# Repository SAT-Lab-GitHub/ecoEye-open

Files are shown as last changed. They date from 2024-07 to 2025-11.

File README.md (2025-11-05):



>[!CAUTION]
>Crrently-shipped openMV H7+ boards run a refactored firmware that is not backwards-compatible with our published scripts. The breaking changes appeared in version 4.5.6 [(more info)](https://forums.openmv.io/t/openmv-firmware-v4-5-6-and-up-tensorflow-porting-guide/9863). The last firmware version that supported our scripts' execution should be 4.3.0 [(official download here)](https://github.com/openmv/openmv/releases/tag/v4.3.0).

Computer-assisted design (CAD) and electronic design automation (EDA) files, as well as micropython scripts (muPy) for building and running ecoEye, an embedded computer-vision camera for ecological applications.

Detailed assembly instructions can be found in the [Wiki](https://github.com/SAT-Lab-GitHub/ecoEye-open/wiki).

The corresponding scientific article is in print. The pre-print is on [BiorXiv](https://www.biorxiv.org/content/10.1101/2023.07.26.550656v1).

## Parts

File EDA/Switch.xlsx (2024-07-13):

Item | Quantity | Reference | Value | Part | Mfg P/N | Size | Supplier Parts | Comment
1 | 1 | U |  | MOSFET P-CH 20V 4A SOT23-3 | DMG3415U-7 | SOT-23-3 | C96616 | P-Channel 20 V 4A (Ta) 900mW (Ta) Surface Mount SOT-23-3
2 | 1 | U1 |  | IC GATE NAND 4CH 2-INP 14TSSOP | MC14093BDG | 14-SOIC | C233506 (https://lcsc.com/product-detail/Gates_onsemi-MC14093BDG_C233506.html) | NAND Gate IC 4 Channel Schmitt Trigger 14-TSSOP
3 | 1 | S2 |  | SWITCH TACTILE SPST-NO 0.05A 24V | B3F-4000 |  | C87494 | Tactile Switch SPST-NO Top Actuated Through Hole
4 | 1 | Q |  | TRANS NPN 45V 0.1A SOT-23 | BC847B | SOT-23-3 | C8575 | Bipolar (BJT) Transistor NPN 100MHz Surface Mount SOT-23-3
5 | 2 | R1, R4 | 1K | RES 1K OHM 0.1% 1/8W 0805 | ERA-6AEB102V | 6-0805_N | C17513 | 1 kOhms ±0.1% 0.125W, 1/8W Chip Resistor 0805 (2012 Metric) Automotive AEC-Q200 Thin Film
6 | 2 | R2, R3 | 100K | RES SMD 100K OHM 0.1% 1/4W 0805 | RP73PF2A100KBTDF | 6-0805_N | C55868 | 100 ±0.1% 0.25W, 1/4W Chip Resistor 0805 (2012 Metric) - Thin Film
7 | 1 | C1 | 0.1 uF | CAP CER 0.1UF 50V X7R 0805 | C2012X7R1H104K085AA | C0805 | C49678 | 0.1 µF ±10% 50V Ceramic Capacitor X7R 0805 (2012 Metric)
9 | 1 | P2 |  |  | 901210764 |  | C293357

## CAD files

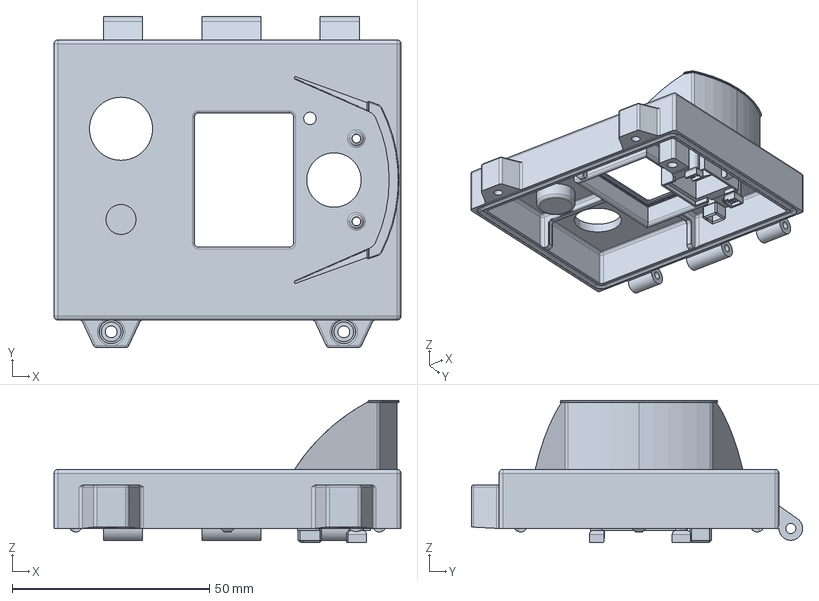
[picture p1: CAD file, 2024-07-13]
CAD/Frontside_V49.stp
88.0 x 84.0 x 36.1 mm

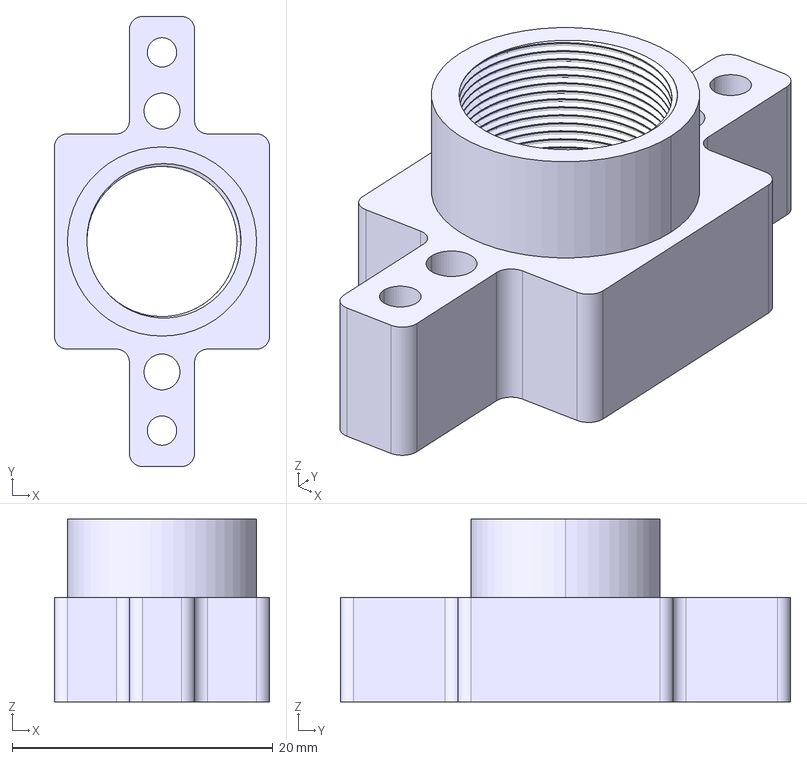
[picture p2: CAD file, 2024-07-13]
CAD/Standalone_Lensmount_thread_V23.stp
16.5 x 34.5 x 14.0 mm

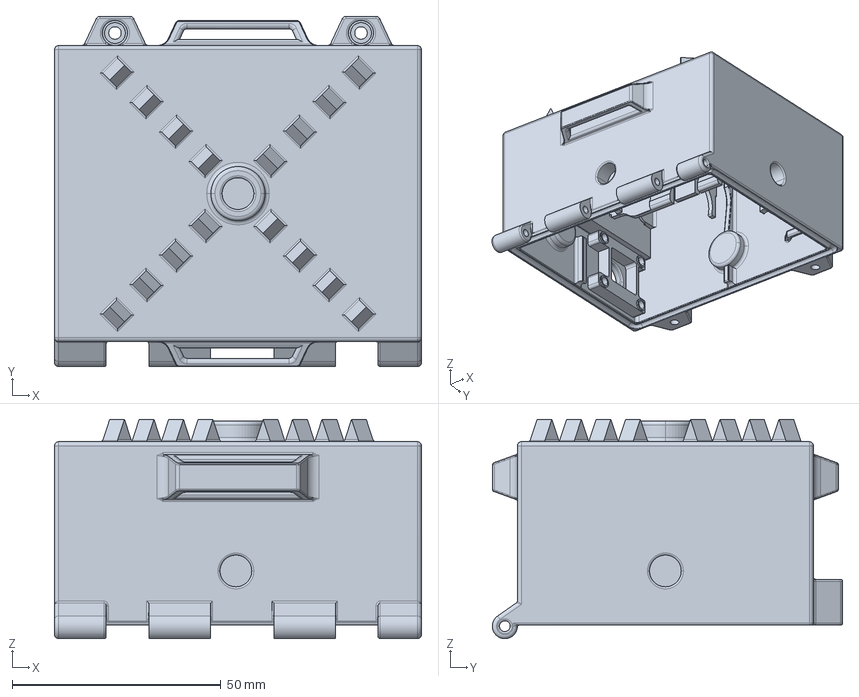
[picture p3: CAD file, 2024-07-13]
CAD/BacksideV49.stp
88.0 x 84.0 x 52.6 mm

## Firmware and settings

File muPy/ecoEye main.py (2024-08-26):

# Blob detection and image classification with whole image, image subsets, ROI, or blob-detected bounding rectangles
# bold character generator : lingojam.com/BoldLetters
# title horizontal lines : copyandpastesymbols.net/line-symbols.html
#import libraries
import sensor, image, time, os, tf, pyb, machine, sys, uos, gc, math
from pyb import Pin, Timer
# import external functions
from ecofunctions import *
# perform quick start from sleep check
start_check()

# ╋╋╋╋╋╋╋╋╋╋ 𝙐𝙎𝙀𝙍-𝘿𝙀𝙁𝙄𝙉𝙀𝘿 𝙋𝘼𝙍𝘼𝙈𝙀𝙏𝙀𝙍𝙎 ╋╋╋╋╋╋╋╋╋╋

# ━━━━━━━━━━ 𝗦𝗛𝗢𝗥𝗧𝗖𝗨𝗧 𝗠𝗢𝗗𝗘𝗦 ━━━━━━━━━━
#operation mode:
#0: live view. Disables saving pictures, frame differencing, classifying, sleeping, bracketing, delay between pictures. Uses auto-exposure.
#1: deploy or test (do not override settings listed below)
#2: live capture. Disables frame differencing, classifying, sleeping, bracketing, delay between pictures. Uses auto-exposure.
MODE = 1

# ━━━━━━━━━━ 𝗚𝗘𝗡𝗘𝗥𝗔𝗟 ━━━━━━━━━━
#camera ID: enter the ID written on the H7+ board's QR code sticker
camera_ID = "00000"
#whether the power management system is used or not
PMS = False
#whether the voltage divider circuit is plugged or not
voltage_divider = False

# ━━━━━━━━━━ 𝗜𝗠𝗔𝗚𝗘 ━━━━━━━━━━
#what resolution to use
sensor_framesize = sensor.WQXGA2
#sensor image format. Options:
#RGB565 = color
#GRAYSCALE = black & white)
sensor_pixformat = sensor.RGB565
#whether to digitally zoom into image
sensor_windowing = False
#introduce delay between pictures (seconds). Otherwise with a delay of 0, the camera runs at maximum speed
delay_loop_s = 0
#for saving whole images or regions of interest (ROIs). Options:
#none: save no picture
#all: save all pictures (fd_enable must be False)
#trigger: save image-change-triggered pictures
#detect: save images with model-detected patterns
save_roi = "all"

# ⚊⚊⚊⚊⚊ windowing mode only parameters ⚊⚊⚊⚊⚊
#rectangle tuples (x,y coordinates and width and height) for digital zoom. x=0,y=0 is conventionally the upper left corner.
#windowing_x=324 corresponds to the point from which a central square crop can be taken while using all the vertical resolution of the sensor
windowing_x = 324
windowing_y = 0
windowing_w = 1944
windowing_h = 1944

# ⚊⚊⚊⚊⚊ advanced settings ⚊⚊⚊⚊⚊
#whether to use user-defined rois (regions of interest)
use_roi = False
rois = [(197,742,782,753),(1309,1320,560,460)]
#whether to control number of frame buffers
sensor_framebuffers_control = False
sensor_framebuffers = 1
#threshold above which the camera goes to sleep between pictures to save power. Below that threshold, the camera will stay on and simply wait
delay_threshold_sleep_s = 10
#set JPEG quality (90: ~1 MB, 95: ~2MB, 100: ~7MB). Hardly discernible improvement above 93
#0: minimum
#100: maximum
jpeg_quality = 95

# ━━━━━━━━━━ 𝗘𝗫𝗣𝗢𝗦𝗨𝗥𝗘 ━━━━━━━━━━
#exposure control mode. Options:
#auto: camera continuously adjusts exposure time and gain, not compatible with frame differencing-based detection
#bias: adjusting exposure and gain automatically at regular intervals (time period can be defined below) but with a user-defined bias for exposure time and gain
#exposure: fixing exposure time, while adjusting gain at regular intervals (time period can be defined below)
#manual: fixing exposure time and gain
exposure_control = "exposure"
#whether to use exposure bracketing
exposure_bracketing = False

# ⚊⚊⚊⚊⚊ bias mode only parameters ⚊⚊⚊⚊⚊
#settings for bias mode: This is the user-defined multiplicative bias for the exposure time. Multiplies the automatic exposure time with this value. Values above 1 brighten the image, values below 1 darken it.
#for instance, if your subject has a bright background (e.g., sky) during the day, you may use values above 1 for the day bias
#if your subject is more strongly illuminated by the IR LEDs than the background during the night, use values below 1 for the night bias
exposure_bias_day = 1
exposure_bias_night = 1
#gain user-bias. Multiplies the automatically-determined gain with this value. Values above 1 brighten the image, values below 1 darken it.
gain_bias = 1
# ⚊⚊⚊⚊⚊ manual or exposure mode only parameters ⚊⚊⚊⚊⚊
#setting for manual and exposure mode:
exposure_ms = 20
#setting for manual mode:
gain_dB = 24

# ⚊⚊⚊⚊⚊ advanced settings ⚊⚊⚊⚊⚊
# How often to adjust exposure, if not in manual or auto mode
expose_period_s = 60
# multiplicative exposure factors used for exposure bracketing, given in tuple. Sequence matters. Lowers frames per second.
exposure_bracketing_values = [1,0.5,2]

# ━━━━━━━━━━ 𝗜𝗟𝗟𝗨𝗠𝗜𝗡𝗔𝗧𝗜𝗢𝗡 𝗟𝗘𝗗 ━━━━━━━━━━
#whether the light shield or IR LED module is installed
#this parameter is only used to determine the voltage divider values
LED_module = False
# which LEDs to use
# module : installed LED module, can be IR or White LEDs
# onboard : use onboard IR LEDs
LED_select = "onboard"
#operation mode for onboard IR or module LEDs at night. Options:
#on: continuously ON during night time . Should be used for continuous illumination with frame differencing
#blink: power-saving intermittent powering on. Should be used to save power, but only when using models to detect targets, since illumination will be unstable
#off: always OFF
LED_mode_night = "off"

# ⚊⚊⚊⚊⚊ LED module only parameters ⚊⚊⚊⚊⚊
#PWM (brightness) of the plug-in LED module
LED_module_PWM = 100
#how long to turn the LED module on (milliseconds) - should possibly not be longer than 3 seconds for IR module
LED_module_warmup = 3000
#how long to turn the LED module off (milliseconds) - should possibly be longer than 5 seconds for IR module
LED_module_cooldown = 0

# ━━━━━━━━━━ 𝗙𝗥𝗔𝗠𝗘 𝗗𝗜𝗙𝗙𝗘𝗥𝗘𝗡𝗖𝗜𝗡𝗚 ━━━━━━━━━━
#whether to use frame differencing. This subtracts every current image from a reference image, resulting in dark images when there is no change.
#a change will introduce a "blob" in the otherwise dark image, which can be detected, logged, and characterised
fd_enable = True

# ⚊⚊⚊⚊⚊ FD enabled only parameters ⚊⚊⚊⚊⚊
#action for blobs. options:
#stop: stop detecting blobs after the first one
#log: log all blobs in detections file
blob_action = "log"
#sensitivity of the blob detection, as measured by the area (number of pixels) of the blobs. Blobs outside this min-max range will not be logged.
#Blob areas can be estimated by drawing rectangular selections on the image preview with the mouse; the area will be displayed below
minimum_blob_pixels = 3000
maximum_blob_pixels = 500000
#color channel thresholds for detection. Pixels with color channel values outside of these ranges will be considered to be blobs.
#requires at least one tuple for grayscale images (for instance: [(0,5)]), three tuples for RGB565 images (for instance: [(0,3),(-3,3),(-3,3)] - this corresponds to LAB channels)
color_thresholds = [(0,5)]

# ⚊⚊⚊⚊⚊ advanced settings ⚊⚊⚊⚊⚊
#whether to export the detected blobs as jpegs (e.g., for gathering training images). options:
#rectangle: exports bounding rectangle
#square: exports bounding square with a side length of the longest side of the blob's bounding rectangle
#none: does not export blobs
export_blobs = "none"
# How much to blend by ([0-256]==[0.0-1.0]). NOTE that blending happens every time exposure is adjusted
background_blend_level = 128

# ━━━━━━━━━━ 𝗡𝗘𝗨𝗥𝗔𝗟 𝗡𝗘𝗧𝗪𝗢𝗥𝗞𝗦 ━━━━━━━━━━
#whether to us neural networks to analyse the image. options:
#image: classify the whole image (i.e. image classification)
#objects: detect (multiple) targets within image (i.e. object detection)
#blobs: classify the blobs (extracted from their bounding rectangles)
#none: do not use neural networks
# TODO give new variable name
classify_mode = "none"

# ⚊⚊⚊⚊⚊ classify enabled only parameters ⚊⚊⚊⚊⚊
#absolute file paths to model and labels files stored on SD card. needs to start with backslash if file is in root
net_path = "/trained.tflite"
labels_path = "/labels.txt"
# model resolution - used for re-scaling before image classification to get a better performance result
model_resolution = 320
#target confidence score above which the image is considered a detection and logged
threshold_confidence = 0.2
#define non-target label names to exclude from image classification results
non_target_labels = "Background"
# --- advanced settings
#minimum image scale for model input
minimum_image_scale = 1
#under which image scale image analysis should be deferred after sunset (with 0.5 overlapping windows in both directions, scale 0.5 takes 8 s, 0.25 takes 40 s, 0.125 takes 3 min)
threshold_image_scale_defer = 0.5

# ━━━━━━━━━━ 𝗜𝗡𝗗𝗜𝗖𝗔𝗧𝗢𝗥𝗦 ━━━━━━━━━━
#whether to show the LED signals and image markings. initialising, waking, sleeping, and regular blinking LED signals, as well as warnings are not affected
indicators = True
#how often to save status log
status_logging_period_ms = 10*60*1000

# ⚊⚊⚊⚊⚊ advanced settings ⚊⚊⚊⚊⚊
#period of blue LED indicating camera is active (in milliseconds, also works when indicators=False)
active_LED_interval_ms = 60*1000
#how long to turn on active LED
active_LED_duration_ms = 500
#how many voltage readings to average over to obtain the value that will be logged
voltage_readings = 10
#how much delay between voltage readings (in milliseconds)
voltage_readings_delay = 10
#minimum voltage for image sensor operation. theoretically, when voltage is below 2.7 V, the image sensor stops working
vbat_minimum = 0
# Add more colors if you are detecting more than 7 types of classes at once
colors = [(255,0,0),(0,255,0),(255,255,0),(0,0,255),(255,0,255),(0,255,255),(255,255,255)]

# ━━━━━━━━━━ 𝗧𝗜𝗠𝗘 𝗔𝗡𝗗 𝗣𝗢𝗪𝗘𝗥 ━━━━━━━━━━
#when the camera should work. options:
#night: during the night (between sunrise and sunset)
#day: during the day (between sunset and sunrise)
#24h: all the time
operation_time = "24h"
# select which RTC to use
# onboard : internal STM32 RTC (10 min offset every 6 hours)
# ds3231 : IR shield v3 shield (green) with ML621 coin cell battery
# pcf8563 : WUV shield (red) with CR1220 coin cell battery
RTC_select = 'onboard'
# For internal RTC, set the current date and time manually (year, month, day, weekday, hours, minutes, seconds, subseconds).
current_date_time = (2022, 9, 15, 0, 18, 33, 35, 0)
#defining operation times for camera, depending on its operation time mode
sunrise_hour = 5
sunrise_minute = 17
sunset_hour = 18
sunset_minute = 34

# ━━━━━━━━━━ 𝗖𝗢𝗡𝗡𝗘𝗖𝗧𝗜𝗩𝗧𝗬 ━━━━━━━━━━
# whether to use WiFi, WiFi shield needs to be installed
wifi_enable = False

# ⚊⚊⚊⚊⚊ wifi enabled only parameters ⚊⚊⚊⚊⚊
# Wifi name and password
wifi_ssid = "MiFiC14646"
wifi_key = "12345678"
# url link to image/data/notification hosting website
wifi_data_url = "https://api.thingspeak.com/update?api_key=WZRWZLO9PRNLY6Y7"
wifi_img_url = "http://potblitd.com/upload.php"
# which data to transfer (ATM only send_confidence is implemented)
send_confidence = False
send_image = False
send_differencing = False
send_voltage = False
#  ⚊⚊⚊⚊⚊ advanced setting ⚊⚊⚊⚊⚊
# confidence above which the image is sent over wifi
threshold_image = 0.5

# ╋╋╋╋╋╋╋╋╋╋ 𝙀𝙉𝘿 𝙊𝙁 𝙐𝙎𝙀𝙍-𝘿𝙀𝙁𝙄𝙉𝙀𝘿 𝙋𝘼𝙍𝘼𝙈𝙀𝙏𝙀𝙍𝙎 ╋╋╋╋╋╋╋╋╋╋

# ━━━━━━━━━━ 𝗦𝗛𝗢𝗥𝗧𝗖𝗨𝗧 𝗠𝗢𝗗𝗘𝗦 ━━━━━━━━━━
# override settings in ine of the shortcut modes
if (MODE == 0 or MODE == 2):
    fd_enable = False
    classify_mode = "none"
    operation_time = "24h"
    exposure_control = "auto"
    delay_loop_s = 0
    exposure_bracketing = False
    RTC_select = 'onboard'
    if (MODE == 0):
        save_roi = "none"
        print("*** Live view enabled! *** ")
    if (MODE == 2):
        save_roi = "all"
        print("*** Live capture enabled! ***")
# or not in normal mode
elif (MODE == 1): print("*** Deployment started! ***")

# ━━━━━━━━━━ 𝗩𝗢𝗟𝗧𝗔𝗚𝗘 𝗗𝗜𝗩𝗜𝗗𝗘𝗥 ━━━━━━━━━━
# resistors values on voltage divider circuits
R_1_PMS_LED = 30
R_2_PMS_LED = 8.82352941176
R_1_PMS_noLED = 30
R_2_PMS_noLED = 100
R_1_noPMS_LED = 2.88
R_2_noPMS_LED = 9.67741935484
R_1_noPMS_noLED = 200
R_2_noPMS_noLED = 680
# set the resistor values in ADC voltage divider
if(PMS):
    if (LED_module):
        R_1 = R_1_PMS_LED
        R_2 = R_2_PMS_LED
    else:
        R_1 = R_1_PMS_noLED
        R_2 = R_2_PMS_noLED
else:
    if (LED_module):
        R_1 = R_1_noPMS_LED
        R_2 = R_2_noPMS_LED
    else:
        R_1 = R_1_noPMS_noLED
        R_2 = R_2_noPMS_noLED

# create voltage divider class
vdiv_bat = vdiv(voltage_divider,voltage_readings,voltage_readings_delay,R_1,R_2)

# ━━━━━━━━━━ 𝗧𝗜𝗠𝗘 𝗦𝗘𝗧/𝗨𝗣𝗗𝗔𝗧𝗘 ━━━━━━━━━━
# create suntime class
solartime = suntime(operation_time,sunrise_hour,sunrise_minute,sunset_hour,sunset_minute)
# initialise RTC object
rtc = pyb.RTC()
# set rtc from user definedc date and time only on power on
if (machine.reset_cause() != machine.DEEPSLEEP_RESET and RTC_select == 'onboard'):
    rtc.datetime(current_date_time)
if(RTC_select == 'ds3231'):
    # import necessary librairies
    from ds3231 import DS3231
    # initialize i2c pins on P7 (SCL) and P8 (SDA) and DS3231 as ext_rtc
    i2c = machine.SoftI2C(sda=pyb.Pin('P8'), scl=pyb.Pin('P7'))
    ext_rtc = DS3231(i2c)
    ext_rtc.get_time(True)
if(RTC_select == 'pcf8563'):
    # import necessary librairies
    from pcf8563 import PCF8563
    # initialize i2c pins on P4 (SCL) and P5 (SDA) and PCF8563 as ext_rtc
    i2c = machine.SoftI2C(sda=pyb.Pin('P5'), scl=pyb.Pin('P4'))
    ext_rtc = PCF8563(i2c)
    ext_rtc.get_time(True)

# print date and time from set or updated RTC
print("Current date (Y,M,D):",rtc.datetime()[0:3],"and time (H,M,S):",rtc.datetime()[4:7])

# ━━━━━━━━━━ 𝗙𝗜𝗟𝗘𝗦 𝗔𝗡𝗗 𝗙𝗢𝗟𝗗𝗘𝗥𝗦 ━━━━━━━━━━
#import mobilenet model and labels before new directory is created
if (classify_mode != "none"):
    net = net_path
    try:
        labels = [line.rstrip('\n') for line in open(labels_path)]
        print("Loaded model and labels")
        #get target label index
        target_indices = [i for i in range(len(labels)) if labels[i] not in non_target_labels]
        non_target_indices = [i for i in range(len(labels)) if labels[i] in non_target_labels]
        print("Selected target indices:",list(labels[i] for i in target_indices))
    except Exception as e:
        print(e)
        raise Exception('Failed to load "trained.tflite" or "labels.txt", make sure to add these files on the SD card (' + str(e) + ')')

# On wakeup from deep sleep, fetch variables from files
if (machine.reset_cause() == machine.DEEPSLEEP_RESET):
    # retrieve current working folder name in VAR
    with open('/VAR/currentfolder.txt', 'r') as folderfetch:
        current_folder = folderfetch.read()
    # retrieve current picture ID in VAR
    with open('/VAR/picturecount.txt', 'r') as countfetch:
        picture_count = eval(countfetch.read())
    # retrieve current detection ID in VAR
    with open('/VAR/detectioncount.txt', 'r') as countfetch:
        detection_count = eval(countfetch.read())

    # check voltage and save status, if battery too low -> sleep until sunrise
    vbat = vdiv_bat.read_voltage()
    save_status(vbat,"Script start - Waking",current_folder)
    if (vbat!="NA" and vbat<vbat_minimum and not pyb.USB_VCP().isconnected()):
        save_variables(current_folder, picture_count, detection_count)
        save_status(vbat,"Battery low - Sleeping",current_folder)
        indicator_dsleep(solartime.time_until_sunrise()+30*60*1000,active_LED_interval_ms)

# create and initialize new folders only on powerup or soft reset
if (machine.reset_cause() != machine.DEEPSLEEP_RESET and MODE != 0):
    # if VAR folder doesnt exists,create new VAR folder
    if (not "VAR" in os.listdir()):
        os.mkdir('VAR')

    # Listing root contents to search folders
    files_jpegs_folder=os.listdir()
    folders=[files_jpegs_folder for files_jpegs_folder in files_jpegs_folder if "." not in files_jpegs_folder]
    if(len(folders)>0):
        folder_number=len(folders)
    else: folder_number=0
    #incrementing folder number (-1 because VAR folder)
    new_folder_number=int(folder_number)-1

    #create folder for new deployment to avoid overwriting images
    folder_created=False
    folder_time = rtc.datetime()
    while (not folder_created):
        try:
            current_folder=str(new_folder_number)+" "+"-".join(map(str,list(folder_time[i] for i in [0,1,2])))+"_"+"-".join(map(str,list(folder_time[i] for i in [4,5,6])))
            os.mkdir(str(current_folder))
            print("Created new deployment folder: "+str(current_folder))
            folder_created=True
        except:
            #increment by 1 if folder already exists, until it doesn't
            new_folder_number=new_folder_number+1

    # Create detection files
    if(not 'detections.csv' in os.listdir(str(current_folder))):
            with open(str(current_folder)+'/detections.csv', 'a') as detectionlog:
                detectionlog.write("detection_id" + ',' + "picture_id" + ',' + "blob_pixels" + ',' + "blob_elongation" + ','
          + "blob_corner1_x" + ',' + "blob_corner1_y" + ',' + "blob_corner2_x" + ',' + "blob_corner2_y" + ',' + "blob_corner3_x" + ',' + "blob_corner3_y" + ',' + "blob_corner4_x" + ',' + "blob_corner4_y"
          + ',' + "blob_l_mode" + ',' + "blob_l_min" + ',' + "blob_l_max" + ',' + "blob_a_mode" + ',' + "blob_a_min" + ',' + "blob_a_max" + ',' + "blob_b_mode" + ',' + "blob_b_min" + ',' + "blob_b_max" + ','
          + "image_labels" + ',' "image_confidences" + ',' + "image_x" + ',' + "image_y" + ',' + "image_width" + ',' + "image_height" + '\n')
    if(not 'images.csv' in os.listdir(str(current_folder))):
        with open(str(current_folder)+'/images.csv', 'a') as imagelog:
            imagelog.write("picture_id" + ',' + "date_time" + ',' + "exposure_us" + ',' + "gain_dB" + ',' + "frames_per_second" + ','
            + "image_type" + ',' + "roi_x" + ',' + "roi_y" + ',' + "roi_width" + ',' + "roi_height" + '\n')
    #make jpeg, reference image and ROI directories if needed
    if (not "jpegs" in os.listdir(str(current_folder))): os.mkdir(str(current_folder)+"/jpegs")
    if (fd_enable and not "reference" in os.listdir(str(current_folder)+"/jpegs")): os.mkdir(str(current_folder)+"/jpegs/reference")
    if (export_blobs!="none" and not "blobs" in os.listdir(str(current_folder)+"/jpegs")): os.mkdir(str(current_folder)+"/jpegs/blobs")
    if use_roi:
        for roi_temp in rois:
            if not '_'.join(map(str,roi_temp)) in os.listdir(str(current_folder)+"/jpegs"): os.mkdir(str(current_folder)+"/jpegs/"+'_'.join(map(str,roi_temp)))
            print("Created",'_'.join(map(str,roi_temp)),"subfolder(s)")

    #start counting
    picture_count = 0
    detection_count = 0

    # check voltage and save status, if battery too low -> sleep until sunrise
    vbat = vdiv_bat.read_voltage()
    save_status(vbat,"Script start - Initialising",current_folder)
    if (vbat!="NA" and vbat<vbat_minimum and not pyb.USB_VCP().isconnected()):
        save_variables(current_folder, picture_count, detection_count)
        save_status(vbat,"Battery low - Sleeping",current_folder)
        indicator_dsleep(solartime.time_until_sunrise()+30*60*1000,active_LED_interval_ms)

# ━━━━━━━━━━ 𝗕𝗢𝗔𝗥𝗗 𝗖𝗢𝗡𝗧𝗥𝗢𝗟 ━━━━━━━━━━
# verify that wifi shield is connected when wifi is enabled
if(wifi_enable):
    wifi_enable = wifishield_isconnnected()
# 50kHz pin6 timer2 channel1
light = Timer(2, freq=50000).channel(1, Timer.PWM, pin=Pin("P6"))
# init led status variables
LED_status = False

# ━━━━━━━━━━ 𝗣𝗜𝗖𝗧𝗨𝗥𝗘 𝗩𝗔𝗥𝗜𝗔𝗕𝗟𝗘𝗦 ━━━━━━━━━━
#user setting checks
if (fd_enable and exposure_control=="auto"):
    print("ATTENTION: using automatic exposure with frame differencing can result in spurious triggers!")
#determine exposure values
if (exposure_bracketing):
    exposure_values=exposure_bracketing_values
else:
    exposure_values=[1]
# ━━━━━━━━━━ 𝗦𝗘𝗡𝗦𝗢𝗥 𝗜𝗡𝗜𝗧 ━━━━━━━━━━
#indicate initialisation with LED
LED_WHITE_BLINK(200,3)
#check night time for continuous monitoring
night_time_check = not solartime.is_daytime()
# Reset and initialize the sensor
sensor.reset()
#we need RGB565 for frame differencing and MobileNet
sensor.set_pixformat(sensor_pixformat)
# Set frame size
sensor.set_framesize(sensor_framesize)
#windowing
if (sensor_windowing):
    sensor.set_windowing(windowing_x,windowing_y,windowing_w,windowing_h)
#set number of frame buffers
if sensor_framebuffers_control: sensor.set_framebuffers(sensor_framebuffers)
# Give the camera sensor time to adjust
sensor.skip_frames(time=1000)
# get future image width and height
if (sensor_windowing):
    image_width=windowing_w
    image_height=windowing_h
else:
    image_width=sensor.width()
    image_height=sensor.height()
#parameter validity checks
if (windowing_y+windowing_h>sensor.height()):
    print(windowing_y)
    print(windowing_h)
    print("sensor height:",sensor.height())
    sys.exit("Windowing height exceeds image height!")
if (windowing_x+windowing_w>sensor.width()):
    sys.exit("Windowing width exceeds image width!")

#assign roi to entire image if we do not use them
if(not use_roi and MODE != 0):
    rois = [(0,0,sensor.width(),sensor.height())]
    if not '_'.join(map(str,rois[0])) in os.listdir(str(current_folder)+"/jpegs"): os.mkdir(str(current_folder)+"/jpegs"+"/"+'_'.join(map(str,rois[0])))
    print("Created",'_'.join(map(str,rois[0])),"subfolder")

#adjusting exposure
# at night, turn ON selected illumination LEDs if not always OFF mode
if(LED_mode_night != "off" and night_time_check and LED_status == False):
    print("Turning illumination LEDs ON for exposure adjustment")
    if(LED_select == 'module'):
        print("Warming up LED module for",LED_module_warmup/1000,"seconds.")
        light.pulse_width_percent(LED_module_PWM)
        sensor.skip_frames(time = LED_module_warmup)
    if(LED_select == 'onboard'):
        LED_IR_ON()
    LED_status = True
expose(exposure_control,exposure_bias_day,exposure_bias_night,gain_bias,exposure_ms,gain_dB,night_time_check)
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

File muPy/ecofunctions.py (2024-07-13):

# Functions for EcoNect
# import libraries
import machine, pyb, time, network, sensor, os, urequests, math
from pyb import Pin, Timer, ExtInt
# import library for interrupt and allocate buffer memory
import micropython

##----- Function description -----#
## Reset and initialize the sensor
##----- Input arguments -----#
## sensor_framesize - resolution for the camera sensor
## sensor_pixformat - pixel format for the camera module
## sensor_windowing -
## sensor_framebuffers_control -
##----- Output variables -----#
## image_width, image_height
#def ecotime(RTC_select):
    #if (RTC_select == 'onboard'):
        #now = pyb.RTC().datetime()
        #return_time = (now[0],now[1],now[2],now[3],now[4],now[5],1,0)
    #if (RTC_select == 'ds3231'):
        #return_time = DS3231(machine.SoftI2C(sda=pyb.Pin('P8'), scl=pyb.Pin('P7'))).get_time()
    #if (RTC_select == 'pcf8563'):
        #from pcf8563 import PCF8563
        #return_time = PCF8563(machine.SoftI2C(sda=pyb.Pin('P5'), scl=pyb.Pin('P4'))).get_time()
    #return return_time

# ━━━━━━━━━━ 𝗖𝗔𝗠𝗘𝗥𝗔 𝗦𝗘𝗡𝗦𝗢𝗥 ━━━━━━━━━━
# ⚊⚊⚊⚊⚊ sensor inititlisation ⚊⚊⚊⚊⚊
# Reset and initialize the sensor
# --- Input arguments ---
# sensor_framesize - resolution for the camera sensor
# sensor_pixformat - pixel format for the camera module
# sensor_windowing -
# sensor_framebuffers_control :
# --- Output variables ---
# image_width, image_height
def sensor_init(sensor_framesize=sensor.QVGA,sensor_pixformat=sensor.RGB565,sensor_windowing=False,sensor_framebuffers_control=False):
    sensor.reset()
    #we need RGB565 for frame differencing and mobilenet
    sensor.set_pixformat(sensor_pixformat)
    # Set frame size
    sensor.set_framesize(sensor_framesize)
    #windowing
    #rect tuples (x,y coordinates and width and height) for digital zoom
    #x=0,y=0 is conventionally the upper left corner
    windowing_x = 324
    windowing_y = 0
    windowing_w = 1944
    windowing_h = 1944
    if (sensor_windowing):
        sensor.set_windowing(windowing_x,windowing_y,windowing_w,windowing_h)
    #set number of frame buffers
    sensor_framebuffers = 1
    if sensor_framebuffers_control: sensor.set_framebuffers(sensor_framebuffers)
    # Give the camera sensor time to adjust
    sensor.skip_frames(time=1000)
    # get future image width and height
    if (sensor_windowing):
        image_width=windowing_w
        image_height=windowing_h
    else:
        image_width=sensor.width()
        image_height=sensor.height()
    # return image width and height
    return image_width, image_height

# ⚊⚊⚊⚊⚊ Adjust exposure ⚊⚊⚊⚊⚊
# Adjust exposure
# --- Input arguments ---
# control - exposure control mode. Options: auto/bias/exposure/manual
# exposure_bias_day - automatic exposure time multiplicator at day
# exposure_bias_night - automatic exposure time multiplicator at night
# gain_bias - automatic exposure time multiplicator
# exposure_ms - manual exposure mode
# gain_dB - manual gain mode
# night_time_check - night time boolean
# LED_select - whether module or onboard LEDs are used
# LED_mode_night - LED mode : always on, always off or blink
# LED_module_warmup - LED startup time
# LED_module_PWM - brightness of the LEDs
# --- Output variables ----
# none
def expose(exposure_control,exposure_bias_day,exposure_bias_night,gain_bias,exposure_ms,gain_dB,night_time_check):
    print("Adjustment of exposure in",exposure_control,"mode...")

    if(exposure_control=="manual"):
        sensor.set_auto_exposure(False, exposure_us = exposure_ms*1000)
        sensor.set_auto_gain(False, gain_db = gain_dB)
        #wait for new exposure time to be applied (is it necessary?)
        sensor.skip_frames(time = 2000)
    elif(exposure_control=="exposure"):
        #enable auto exposure and gain
        sensor.set_auto_gain(True)
        sensor.set_auto_exposure(False, exposure_us = exposure_ms*1000)
        #wait for auto gain
        sensor.skip_frames(time = 2000)
        #fix the gain so image is stable for frame differencing
        sensor.set_auto_gain(False, gain_db = sensor.get_gain_db())
    elif(exposure_control=="bias"):
        if night_time_check: exposure_bias=exposure_bias_night
        else: exposure_bias=exposure_bias_day
        #enable auto exposure and gain
        sensor.set_auto_exposure(True)
        sensor.set_auto_gain(True)
        #wait for auto settings to kick in
        sensor.skip_frames(time = 2000)
            #apply bias
        sensor.set_auto_exposure(False, \
            exposure_us = int(sensor.get_exposure_us() * exposure_bias))
        sensor.set_auto_gain(False, \
            gain_db = sensor.get_gain_db() * gain_bias)
        #wait for bias to be applied
        sensor.skip_frames(time = 2000)
        # TODO:possibly turn off LEDs here if it works with subsequent fd function and image capture
    return

# ━━━━━━━━━━ 𝗦𝗗 𝗖𝗔𝗥𝗗 𝗦𝗔𝗩𝗜𝗡𝗚 ━━━━━━━━━━
# ⚊⚊⚊⚊⚊ save status log ⚊⚊⚊⚊⚊
# Save status log
# --- Input arguments ---
# vbat - voltage of batteries
# status - user-defined string describing the status to save in the log
# pathstr - path of the folder, string type
# --- Output variables ---
# none
def save_status(vbat,status="NA",folder='/'):
    print("Saving '",status,"' into status log.")
    adc  = pyb.ADCAll(12)
    if(not 'status.csv' in os.listdir(str(folder))):
        with open(str(folder)+'/status.csv', 'a') as statuslog:
            statuslog.write("date_time" + ',' + "status" + ',' + "battery_voltage" + ',' + "USB_connected" + ',' + "core_temperature_C" + '\n')
    with open(str(folder)+'/status.csv', 'a') as statuslog:
        statuslog.write(str("-".join(map(str,time.localtime()[0:6])))+ ',' + status + ',' + str(vbat) + ',' + str(pyb.USB_VCP().isconnected()) + ',' + str(adc.read_core_temp()) + '\n')
    return

# ⚊⚊⚊⚊⚊ save variables ⚊⚊⚊⚊⚊
# save the dynamic variables in the VAR folder
# --- Input arguments ----
# current_folder - name of the current folder
# picture_count - name/number of the current picture
# detection_count - name/number of the current detection
# --- Output variables ---
# none
def save_variables(current_folder, picture_count, detection_count):
    # create file in VAR folder and write current folder name
    with open('/VAR/currentfolder.txt', 'w') as folderlog:
        folderlog.write(str(current_folder))
    # create file on root and write current picture ID
    with open('/VAR/picturecount.txt', 'w') as countlog:
        countlog.write(str(picture_count))
    # create file on root and write current detection ID
    with open('/VAR/detectioncount.txt', 'w') as countlog:
        countlog.write(str(detection_count))
    return
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

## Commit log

2024-08-26 Update ecoEye main.py
    corrected typos
    [ecoEye main.py]
2024-09-06 Delete CAD/random
    removed dummy file
